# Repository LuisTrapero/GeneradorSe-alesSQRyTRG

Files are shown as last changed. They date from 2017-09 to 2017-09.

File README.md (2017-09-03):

# Generador Señales V1.0
Pequeño circuito diseñado en KiCad para generar señales cuadrada y triangular en fase. El circuito consta de cuatro partes:

1. **Un oscilador:** Empleamos el oscilador del circuito integrado CD4046 para generar una señal cuadrada de frecuencia variable. La frecuencia de las señales se puede ajustar mediante un potenciómetro o mediante una tensión externa al circuito.
2. **Un sumador:** para poder modificar el offset de la señal a nuestro gusto proponemos emplear un circuito sumador que utiliza como entrada la alimentación negativa de los amplificadores operacionales.
3. **Un integrador:** Tras dejar el offset de la señal cuadrada en 0V ya está preaparada para pasar por el integrador y convertirse en una señal triangular.
4. **Un divisor de tensión:** un simple instrumento para controlar la amplitud de la señal triangular.

Por comodidad en el montaje, la placa está diseñada para componentes through-hole.

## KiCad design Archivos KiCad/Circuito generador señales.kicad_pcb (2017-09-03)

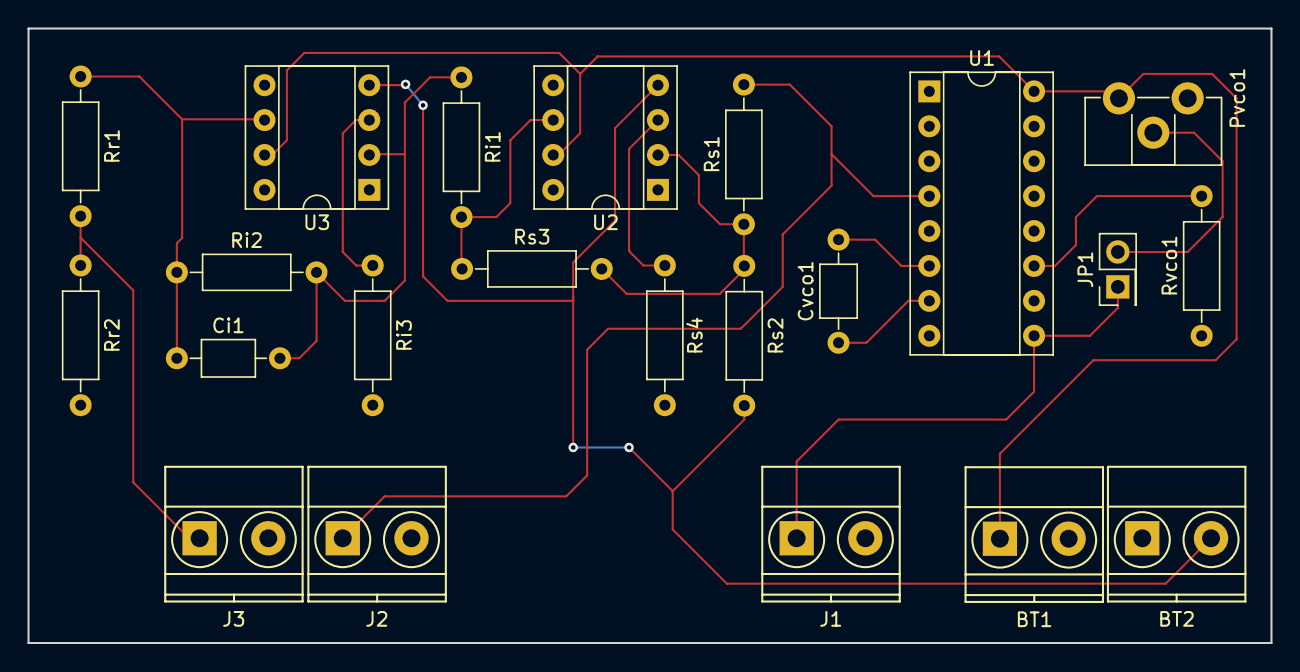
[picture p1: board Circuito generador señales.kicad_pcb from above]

Board: 2 copper layers, 90.4 x 44.7 mm, 22 parts (0 on the bottom side), 16 nets.

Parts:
BT1: +5; TerminalBlock_Pheonix_MKDS1.5-2pol
BT2: -5; TerminalBlock_Pheonix_MKDS1.5-2pol
Ci1: 10n; C_Axial_L3.8mm_D2.6mm_P7.50mm_Horizontal
Cvco1: 100p; C_Axial_L3.8mm_D2.6mm_P7.50mm_Horizontal
J1: VCOin; TerminalBlock_Pheonix_MKDS1.5-2pol
J2: SQR; TerminalBlock_Pheonix_MKDS1.5-2pol
J3: TRNG; TerminalBlock_Pheonix_MKDS1.5-2pol
JP1: Jumper; Pin_Header_Straight_2x01_Pitch2.54mm
Pvco1: 10k; Potentiometer_Trimmer_ACP_CA9h2.5_Vertical_Px2.5mm_Py5.0mm
Ri1: 1.25k; R_Axial_DIN0207_L6.3mm_D2.5mm_P10.16mm_Horizontal
Ri2: 8k; R_Axial_DIN0207_L6.3mm_D2.5mm_P10.16mm_Horizontal
Ri3: 1k; R_Axial_DIN0207_L6.3mm_D2.5mm_P10.16mm_Horizontal
Rr1: 74.8k; R_Axial_DIN0207_L6.3mm_D2.5mm_P10.16mm_Horizontal
Rr2: 1k; R_Axial_DIN0207_L6.3mm_D2.5mm_P10.16mm_Horizontal
Rs1, Rs3: 10k; R_Axial_DIN0207_L6.3mm_D2.5mm_P10.16mm_Horizontal
Rs2: 20k; R_Axial_DIN0207_L6.3mm_D2.5mm_P10.16mm_Horizontal
Rs4: 1k; R_Axial_DIN0207_L6.3mm_D2.5mm_P10.16mm_Horizontal
Rvco1: 100k; R_Axial_DIN0207_L6.3mm_D2.5mm_P10.16mm_Horizontal
U1: 4046; DIP-16_W7.62mm_Socket
U2, U3: TL081; DIP-8_W7.62mm_Socket

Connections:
/-5V: BT2.2, Rs2.2, U2.4, U3.4
GND: BT1.2, BT2.1, J1.2, J2.2, J3.2, Pvco1.1, Ri3.2, Rr2.2, Rs4.2, Rvco1.1, U1.5, U1.8
unnamed: Ci1.1, Ri2.1, Rr1.1, U3.6
unnamed: Ci1.2, Ri1.1, Ri2.2, U3.2
unnamed: Cvco1.1, U1.7
unnamed: Cvco1.2, U1.6
unnamed: J1.1, JP1.1, U1.9
unnamed: J2.1, Rs1.2, U1.4
unnamed: J3.1, Rr1.2, Rr2.1
unnamed: JP1.2, Pvco1.2
unnamed: Ri1.2, Rs3.1, U2.6
unnamed: Ri3.1, U3.3
unnamed: Rs1.1, Rs2.1, Rs3.2, U2.2
unnamed: Rs4.1, U2.3
unnamed: Rvco1.2, U1.11
VDD: BT1.1, Pvco1.3, U1.16, U2.7, U3.7

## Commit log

2017-09-03 Añadidos archivos KiCad
    [Circuito generador señales-B.Cu.gbr, Circuito generador señales-B.Mask.gbr, Circuito generador señales-B.SilkS.gbr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]
2017-09-03 Añadidas Datasheets de CIs
2017-09-10 Changed the structure of the repositories
    [Circuito generador señales-B.Cu.gbr, Circuito generador señales-B.Mask.gbr, Circuito generador señales-B.SilkS.gbr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]
